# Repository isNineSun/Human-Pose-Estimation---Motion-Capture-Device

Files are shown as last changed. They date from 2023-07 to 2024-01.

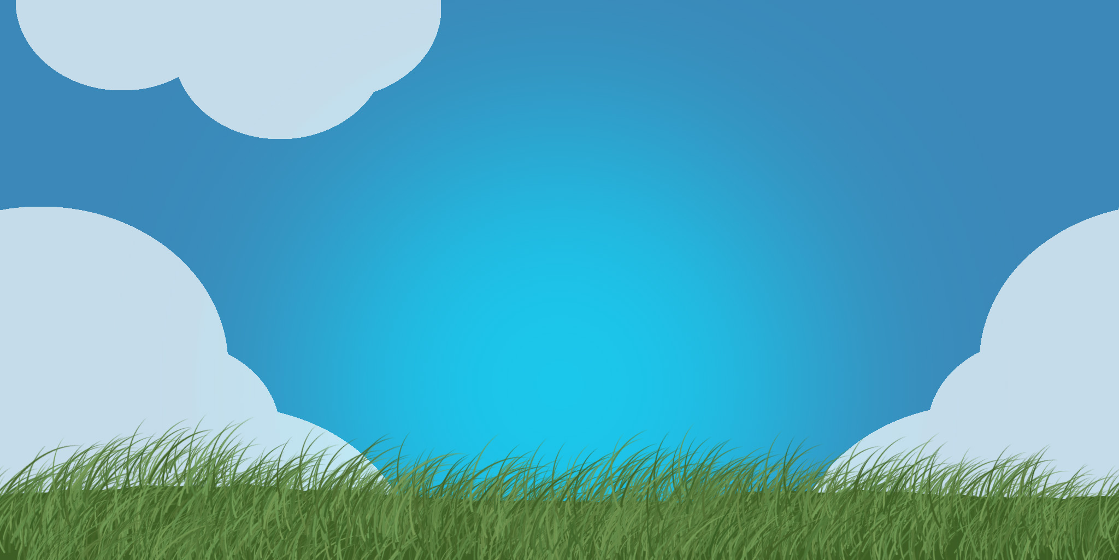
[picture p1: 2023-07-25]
Unity/Assets/TextMesh Pro/Examples & Extras/Textures/Sunny Days - Seamless.jpg

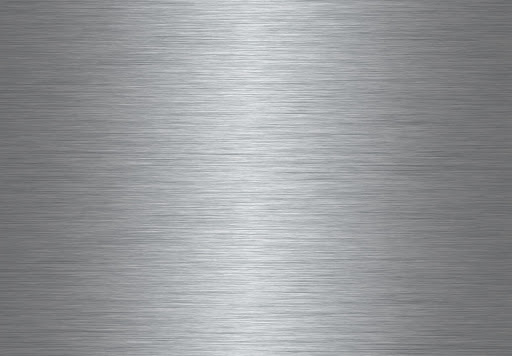
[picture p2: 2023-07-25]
Unity/Assets/TextMesh Pro/Examples & Extras/Textures/Brushed Metal 3.jpg

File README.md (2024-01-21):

# Human Pose Estimation - Motion Capture Device
## 摘要

最近比较沉迷虚拟主播，用来打发时间还是挺有意思的，一些3D势虚拟主播不可避免的就是会使用到动作捕捉设备，产生了一些兴趣，想简单实现一下。现在市面上大多数的动补方案是光学动补、惯性动补和混合动补三种方式，光学动补精度高，但是成本也高，而且捕捉质量与摄像头帧率和数量直接相关，惯性动补成本相对比较低，但是会不可避免的有各种漂移问题，成品商业方案大多是最后一种，是光学和惯性结合起来去做拟合，从而达成比较好的稳定性和精度。光学动补现在已经有很多商业公司开放付费使用的服务了，比如小K动补之类的，所以本文就 **不介绍光捕，而实现一个惯性动补**。    
<!-- more -->

## 1.设计思路&硬件选择
我希望动捕设备最好能无线连接PC，所以esp32就成了首选，不用再多加一个透传模块，而且价格也便宜，另外就是IMU的选型，这个的选择项就非常多了，一些精度高的IMU价格非常夸张，所以这里就使用最常见的六轴IMU MPU6050，物美价廉，漂移和噪声问题确定很大，但是可以放在软件算法里去尽量做优化，不过调过姿态控制的都知道，六轴传感器的偏航角几乎是不可用的，这是六轴传感器工作机制导致的，只能用角速度去积分获取偏航角，然后一定程度上通过横滚角和俯仰角去矫正，理想的状态下，静态响应还是凑合的，但是动态响应几乎就是灾难，在动捕这个领域，这显然是不合适的，因此为了获得更为准确的yaw角度，我选择添加一个磁力计，HMC5883L，虽然磁力计也同样会有被环境干扰问题，比如周围的磁场，但是它的yaw角很大程度上至少是可信的，环境干扰也可以放在软件算法里面去尽量矫正。
所以最后确定的下位机方案就是使用esp32+mpu6050+HMC5883L,成本大概30块钱左右，然后关于上位机的选择，因为这次涉及到3D模型，当然是请出老朋友unity，下位机采集解算出来的欧拉角直接通过wifi与PC走UDP（延时小）通信传输数据，然后再在PC端根据欧拉角还原人体姿态，大致思路就是这个样子。       

## 2.硬件设计
硬件方面IMU直接用的是模块，因为裸片买不起（悲），然后尺寸尽可能小巧，没有画成两面板是因为就算把尺寸再画小一点，电池容量也可能不太够了，索性定在了45mm * 45mm的尺寸上了能一面画完，能放一个800mah的锂电池，项目工程都再立创开源了，以下是链接：   
[立创开源广场项目链接](https://oshwhub.com/isninesun/hpsv204)

### PCB Layout


## 3.软件设计    
### 3.1 设备软件
由于IMU和磁力计采集到的数据都是有很大噪声的，而且消费级的IMU的漂移问题很严重，所以他们的数据直接拿来其实是不能用的，上面那段代码其实是一个卡尔曼滤波的处理，也算是姿态解算中很经典的处理算法了，具体的原理就不在这里展开了，关于卡尔曼滤波的教程和讲解网上有太多太多，我就不在这里班门弄斧了，卡尔曼滤波主要针对IMU，可以得到一个可用的Roll角和Pitch角，而Yaw角则需要用磁力计来解决，磁力计在外部坏境相对稳定的情况下，指北的表现还是比较好的，所以只对其数据进行简单的均值滤波其实在平面上就已可用，其问题在于倾斜情况下需要对磁偏角进行倾斜校正，不然会得到一个完全错误的数值，原因跟磁力计的工作方式有关，在此不多赘述，感兴趣可以看这篇文章了解其原理[基于加速度计与磁力计的姿态解算方法(加计补偿偏航)](https://zhuanlan.zhihu.com/p/61765669。)。最后将获得的Roll、Pitch、Yaw角传出，后面的工作就是组报文 + UDP通信了，将数据传给PC上位机后，再由PC去根据欧拉角还原物体姿态。    

### 3.2 上位机软件
如上面所说，上位机我用的是Unity，这里其实没有太多可说的，上位机全部的工作就是建立一个UDP的服务器，接收来自设备的包含欧拉角信息的消息并对其进行解析，然后使用角度信息对场景物体进行对应旋转，真要说的话，本文只是Part1，所以只做了一个Cube去做测试，具体人体姿态的解算和还原会放在Part2中去详细说明。上位机的Unity工程我也放在了Github仓库中。    

## 4.效果演示
这里放一张动图用来展示实际的效果：    


## 5.上位机展示
上位机基于Unity制作，用的是传统的正向动力学，上位机的开源仓库请点击-->[动作捕捉配套上位机](https://github.com/isNineSun/Motion-Capture-Host-Software.git)，后续也有兴趣涉足一下IK，暂时学习用效果如下了。    
https://github.com/isNineSun/Human-Pose-Estimation---Motion-Capture-Device/assets/42261713/1a74626f-e1af-4e56-bceb-0fe2316b3c24

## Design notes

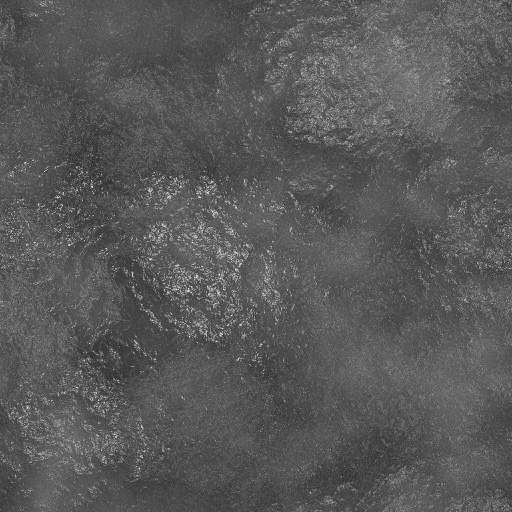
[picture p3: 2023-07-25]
Unity/Assets/TextMesh Pro/Examples & Extras/Textures/Fruit Jelly (B&W).jpg

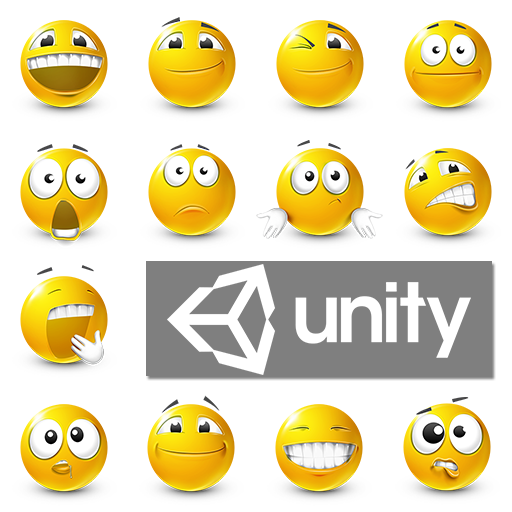
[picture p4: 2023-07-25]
Unity/Assets/TextMesh Pro/Examples & Extras/Sprites/Default Sprites.png

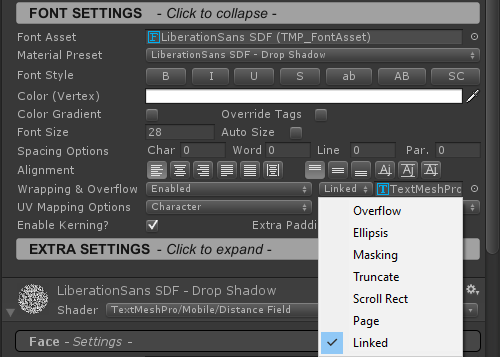
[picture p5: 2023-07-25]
Unity/Assets/TextMesh Pro/Examples & Extras/Textures/Text Overflow - Linked Text UI Screenshot.png

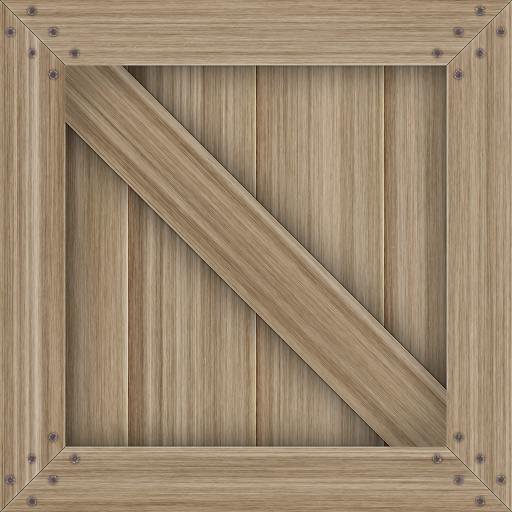
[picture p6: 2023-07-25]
Unity/Assets/TextMesh Pro/Examples & Extras/Textures/Small Crate_diffuse.jpg

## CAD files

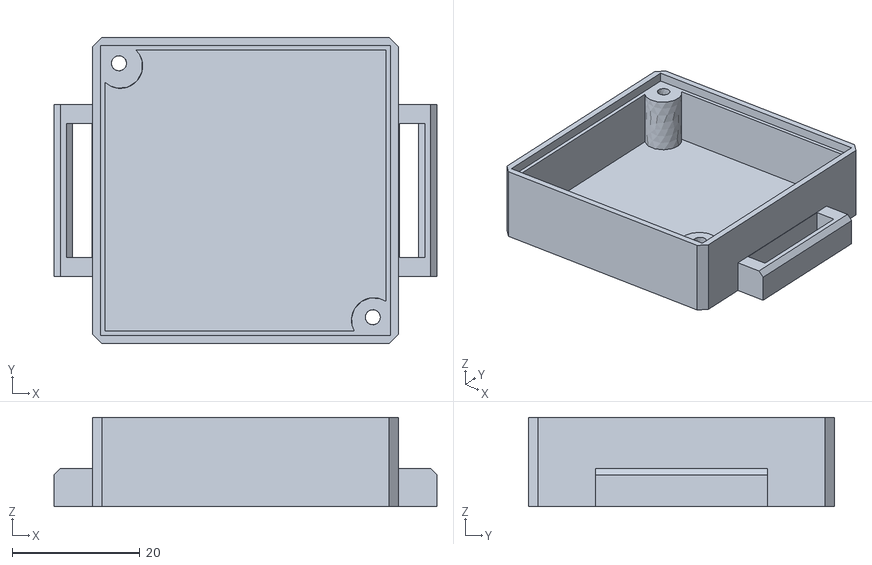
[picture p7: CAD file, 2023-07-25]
3D_Printed_Case/Box_T.stl
60.0 x 48.0 x 14.0

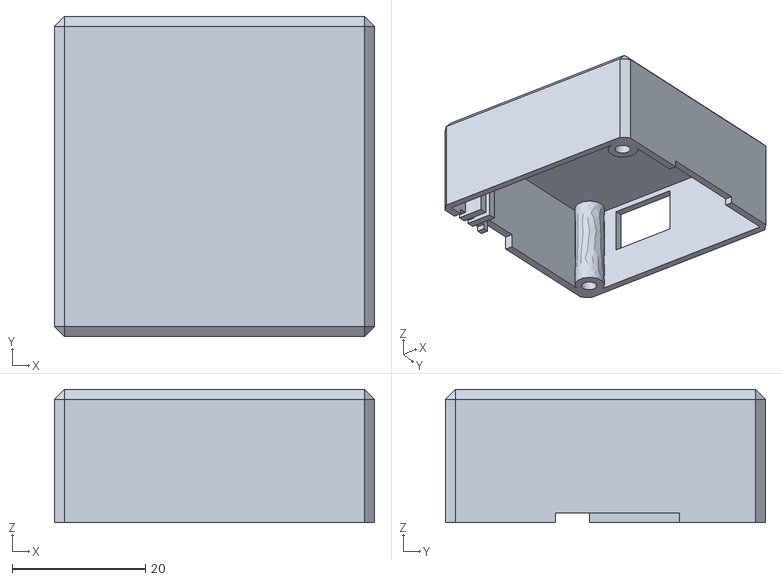
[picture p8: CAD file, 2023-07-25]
3D_Printed_Case/Box_B.stl
48.0 x 48.0 x 20.0

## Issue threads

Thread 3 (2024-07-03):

如何处理初始化校准与关节坐标系不一致问题？

BestPolarBear, 2024-07-03:
请问您一下，你是如何处理初始化校准、传感器佩戴便宜、人物模型关节坐标系不一致等问题，期待您的回复，Thanks!

isNineSun, 2024-08-31:
不好意思，我不常看github，一直没看到你的回复。
首先需要声明是，这是个做来玩玩的项目，可能对你的问题并没有一个很完善的解决方案，很多东西比较将就，你可以参考更成熟的项目比如slimVR项目。

**初始化校准的问题**：在佩戴前需要设备尽可能水平放置，校准后才进行佩戴，很久之前写的代码记忆有点模糊，我记得代码中会取1000组（大概）数据去计算offset。
**佩戴偏移问题**：这个我完全没做软件的解决方案，就我所知，索尼之前推出的那个成品的动捕设备，也是需要佩戴规范的。
**任务关节坐标系问题**：这个我在另一个上位机的项目里面有提到，我模型里面用的是传统的正向运动学，在Unity里面任务的关节作为上一个关节的子节点，人物在T-Pose的状态下，每个子物体的初始坐标就是0，我只需要将三个角度以合适的方式赋值给他们就可以了，但这就要求人体捕捉的设备跟对应关节是一一绑定的，因为每个关节对roll pitch和yaw的处理方案都不相同，这里的处理主要在上位机的部分。同样对应参考别的成品动捕方案，在开始之前也是需要人物和模型做一个或者几个姿势的Check的。

Closed 2024-09-15.

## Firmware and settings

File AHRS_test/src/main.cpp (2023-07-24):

#include <Arduino.h>
#include <Wire.h>
#include <Ticker.h>

#include <Solution_algorithm.h>
#include <Madgwick.h>
#include <init.h>
#include <wifi_connection.h>
#include <bluetooth.h>
#include <led.h>

#define MADGWICK
#define MAX_BUF_CNT 128

Ticker timer;

char buffer[MAX_BUF_CNT];
int buf_len = 0;
float roll = 0, pitch = 0, yaw = 0;

static void Send_MSG();

void setup()
{
    /*打开串口和实现I2C通信*/
    Wire.begin(23, 5);//SDA->23,SCL->5

    Serial.begin(115200);
    
    MPU6050_setup_init();
    HMC5883L_setup_init();

#ifdef _WIFI_COMMUNICATION_
    wifi_setup();
#endif

#ifdef _BLUETOOTH_COMMUNICATION_
    bluetooth_setup();
#endif

    timer.attach(0.02f, Send_MSG);

#ifndef _MADGWICK_ALGORITHM_
    //计算偏移量
    offset_init();
#else
    Madgwick_init();
#endif

    delay(100);
}

void loop()
{
#ifndef _MADGWICK_ALGORITHM_
    get_Euler_angle(&roll, &pitch, &yaw);
#else
    get_Euler_angle_by_madgwick(&roll, &pitch, &yaw);
    //get_Euler_angle_by_madgwick_simple(&roll, &pitch, &yaw);
#endif

}


static void Send_MSG() 
{
#ifdef _BLUETOOTH_COMMUNICATION_
    blutooth_send_mag(roll, pitch, yaw);
#endif

#ifdef _WIFI_COMMUNICATION_
    wifi_communication_send_msg_loop(roll, pitch, yaw);
#endif
}

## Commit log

2023-07-25 3D printed case moudle
    [Box_B.stl, Box_T.stl]
2024-01-21 更新描述
